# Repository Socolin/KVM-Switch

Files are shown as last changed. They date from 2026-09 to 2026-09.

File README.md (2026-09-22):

# KVM Switch

A KVM Switch for any HID device built with multiple [Raspberry Pi Pico 2](https://www.raspberrypi.com/products/raspberry-pi-pico-2/)

## Status

This project is still in development. The code is almost done, and I need to design the PCB.

Photo of the KVM Switch on a breadboard

So far I can use it as a KVM switch. I can select the computer to use with a keyboard shortcut. I was not able to
test with exotic keyboard / mouse yet, but those should be supported.

The detailed documentation is available at [doc/technical.md](doc/technical.md).

The remaining tasks are: 
- Test with 2 nodes (switch between 3 computers).
- Design PCB for 1 node (and maybe for 2 nodes later)
- Test with 3 hid devices.
- Test `TUD_OPT_HIGH_SPEED`

## Build

### Prerequisites

- cmake
- Clone https://github.com/raspberrypi/pico-sdk
- Clone https://github.com/raspberrypi/picotool

### Build

```sh
git clone git@github.com:Socolin/KVM-Switch.git
cd KVM-Switch
git submodule update --init --recursive
mkdir build
cd build
cmake .. -DPICO_BOARD=pico2 -DPICO_SDK_PATH={PATH_TO_PICOSDK} -DPICOTOOL_FETCH_FROM_GIT_PATH={PATH_TO_PICOTOOL}
make -j
# Then output is in src/node and src/controller
```

### Flash

To simplify flashing both, you can use the serial number of your pico with `picotool info -a` the serial will look like `46AA0E6255B66826`

```sh
picotool load --ser $PICO_PI_NODE_SERIAL -f -x src/node/kvm_node.uf2;
picotool load --ser $PICO_PI_CONTROLLER_SERIAL -f -x src/controller/kvm_controller.uf2;
```

## Hardware Architecture

### 2 Nodes With 2 HIDs

[See Schematic](doc/2_nodes_2_hid/2_nodes_2_hid.pdf)

### 2 Nodes With 3 HIDs

[See Schematic](doc/2_nodes_3_hid/2_nodes_3_hid.pdf)

### 3 Nodes With 3 HIDs

[See Schematic](doc/3_nodes_3_hid/3_nodes_3_hid.pdf)

## Software Architecture

Diagram showing the software architecture of the project. Detailing which core execute which part and which the architecture of node and controller boards

## Configuration UI

The KVM Switch can be configured through a web UI. It can be accessed with a web browser supporting WebUSB.
You can access it at https://socolin.github.io/KVM-Switch/ (You need to use a browser supporting WebUSB)
The code of the config UI is in `tools/configurator`

Web UI

### Build

If you need to build the tool, you need [Node.js 24](https://nodejs.org/) then run those commands

```
cd tools/configurator
npm install
npm run start
```

Then access it at http://localhost:4200 (You need to use a browser supporting WebUSB)

## AI Usage

Basically, I see AI as a tool, and I have fun writing code, so:

- All the code in `src/` is written by a human.
- AI was used as a learning assistant, to help understand and learn all the USB / HID / Electronic stuff.
- AI was used to review the code.
- AI was used to generate some test cases (but the test logic is human-made) (see `AI-generated` comments).

## History

This project started to fix an issue I had with my current commercial KVM switch, that is the delay to switch between
2 computers; I wanted a shortcut to switch instantaneously. This project is also an opportunity for me to learn a some
few things with electronic and discover dev on a microcontroller. Feel free to provide any feedback, as I'm still
learning.

I first tried to use CH9329 and CH9350 to avoid all the USB parts and get this done quickly. However, during
my testing I discovered that the CH9329 has a HID descriptor that does not expose all the features I wanted (like the
mouse pan) and the CH9350 felt the same way. So I learnt a lot about HID descriptors, tinyUSB, etc… And, now this project
should support any HID device (not just keyboard and mouse) like Gamepad etc… I kept the code I used to use those chips
in `src/legacy` if anyone need this, feel free to use it

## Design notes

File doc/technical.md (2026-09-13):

# Technical

## Controller / Node

Each Pico PI 2 can handle one USB Device. So to connect the KVM Switch to multiple computers, 1 Pico PI is used per
computer.

The main Pico is the one with the USB ports for the HID devices, it's named the Controller (`src/controller`), and any
additional pico pi is named a Node (`src/node`).

The Controller and the Nodes are communicating using SPI. On the Controller it's using the `spi0` with the default pins
And on the first nodes it's using the `spi1` with the GPIO 12,13,14,15 to simplify cable management between the two
boards.

Each node also uses 2 GPIO:

- `spi_ready_gpio` use to notify the Controller when the node is listening on SPI and the controller can communicate
  with them.
- `data_available_gpio` use to notify the Controller when the node has data available to be read.

When there are two or more nodes, the controller uses another GPIO (`spi_selector_gpio`) to select which node to
communicate with.

When the Controller boots, it restarts all the nodes (with GPIO 15 connected to `RUN` on the nodes) and waits for them
to be ready (Waiting for an `GPIO_IRQ_EDGE_RISE` event on `spi_ready_gpio`)

## USB Device – Connected to a computer

See `usb_device.c`

The USB Port used to act as a USB device from a computer point of view is the micro USB port that comes with the
PICO-PI.
This allows running some logic on the same core that handles this usb port with Tiny USB, since this USB port is managed
by the RP2350 the timings are not as critical as when using Pico-PIO-USB.

## USB Host – Connected to the HID Devices (Keyboard / Mouse / ...)

See `usb_host.c`

The USB Host part is used to handle the HID Devices plugged into the KVM Switch. Pico-PIO-USB with TinyUSB is used to
handle the USB communication with the HID Devices. And the Core 1 on the Controller is dedicated to handle the USB
communication with the HID Devices.

The USB ports have both D+ and D-, pulled down to act as a USB host.

## HID Devices

The HID devices are connected to the USB Host part of the Controller. When a HID device is mounted, the controller reads
the HID report descriptor for every HID interface and then exposes the report descriptors as its own on the computer
side (see `hid_manager.c`). Then, when an HID Device is sending a report (when a key is pressed, for example), the
report is forwarded as-is to the selected computer.

The HID report descriptor is also decoded (see `hid_report_descriptor.c`) and any keyboard report is then interpreted to
detect if a shortcut has been pressed (see `kvm_switch_config.c`).

## WebUSB

See `web_usb_handler.c`

To allow a simple configuration of the KVM Switch, WebUSB is used to communicate with the KVM Switch from a web browser.
A Vendor interface is exposed to the computer (see `#if CFG_TUD_VENDOR` blocks in `usb_device.c`).

When a config is changed, the config is then saved to the flash. It's written on the fourth sector from the end of the
flash (see `config_persistence.c`).

## Cpu Core Usage

On the controller core 0 runs the main logic, core 1 is dedicated to handle the USB communication with the HID Devices.
On the nodes, core 0 runs the main logic, and core 1 is dedicated to the SPI communication with the controller.

## System clock

The system clock is set to 144 MHz because Pico-PIO-USB needs a multiple of 12 MHz.

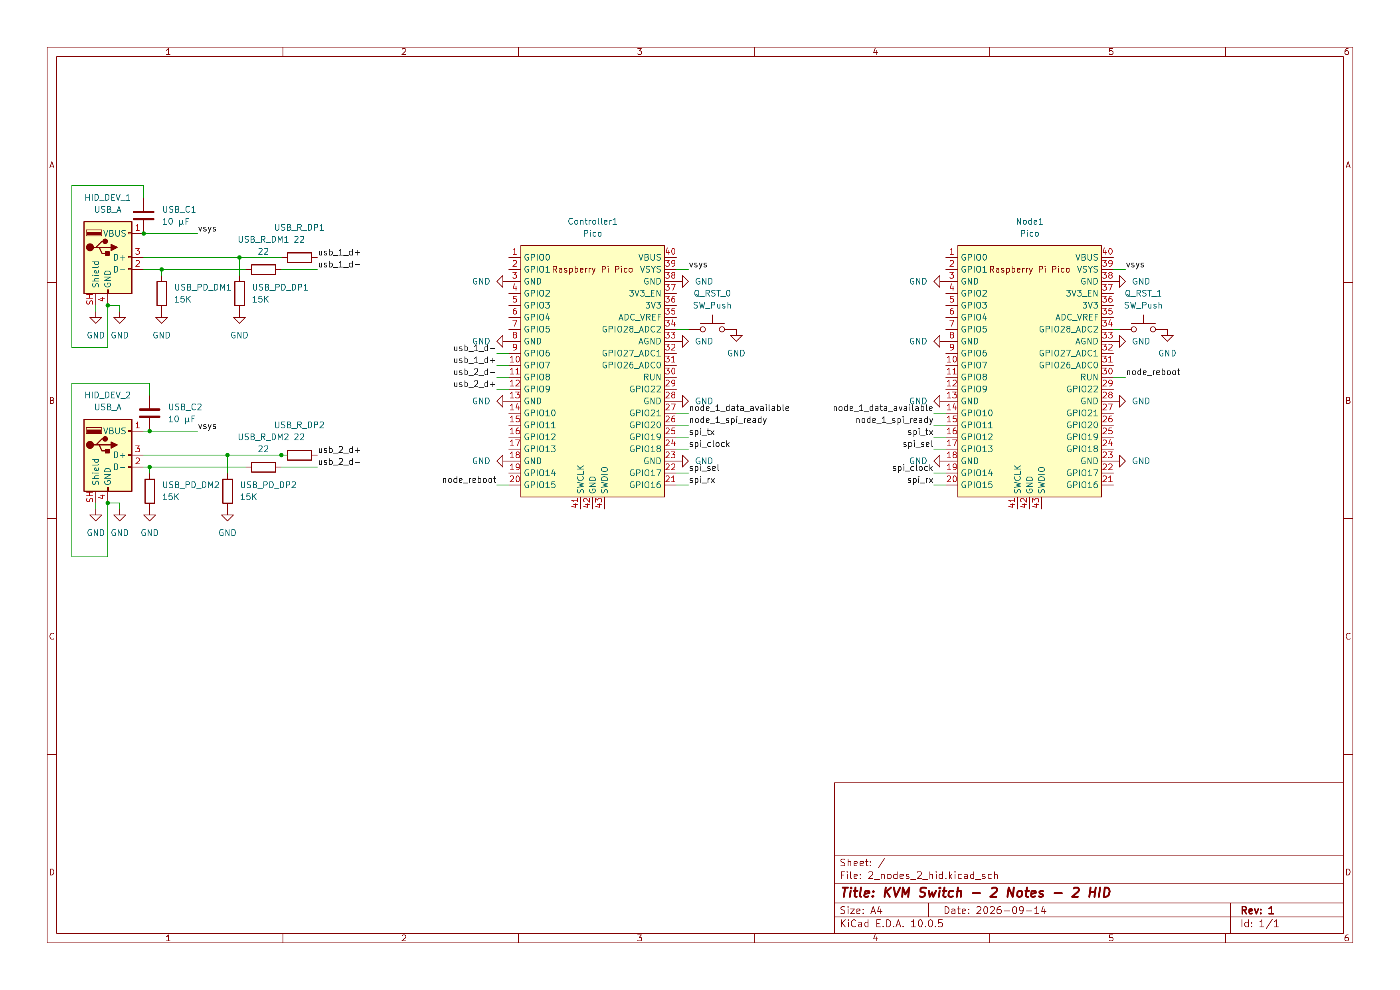
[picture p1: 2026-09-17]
doc/img/schematic.png

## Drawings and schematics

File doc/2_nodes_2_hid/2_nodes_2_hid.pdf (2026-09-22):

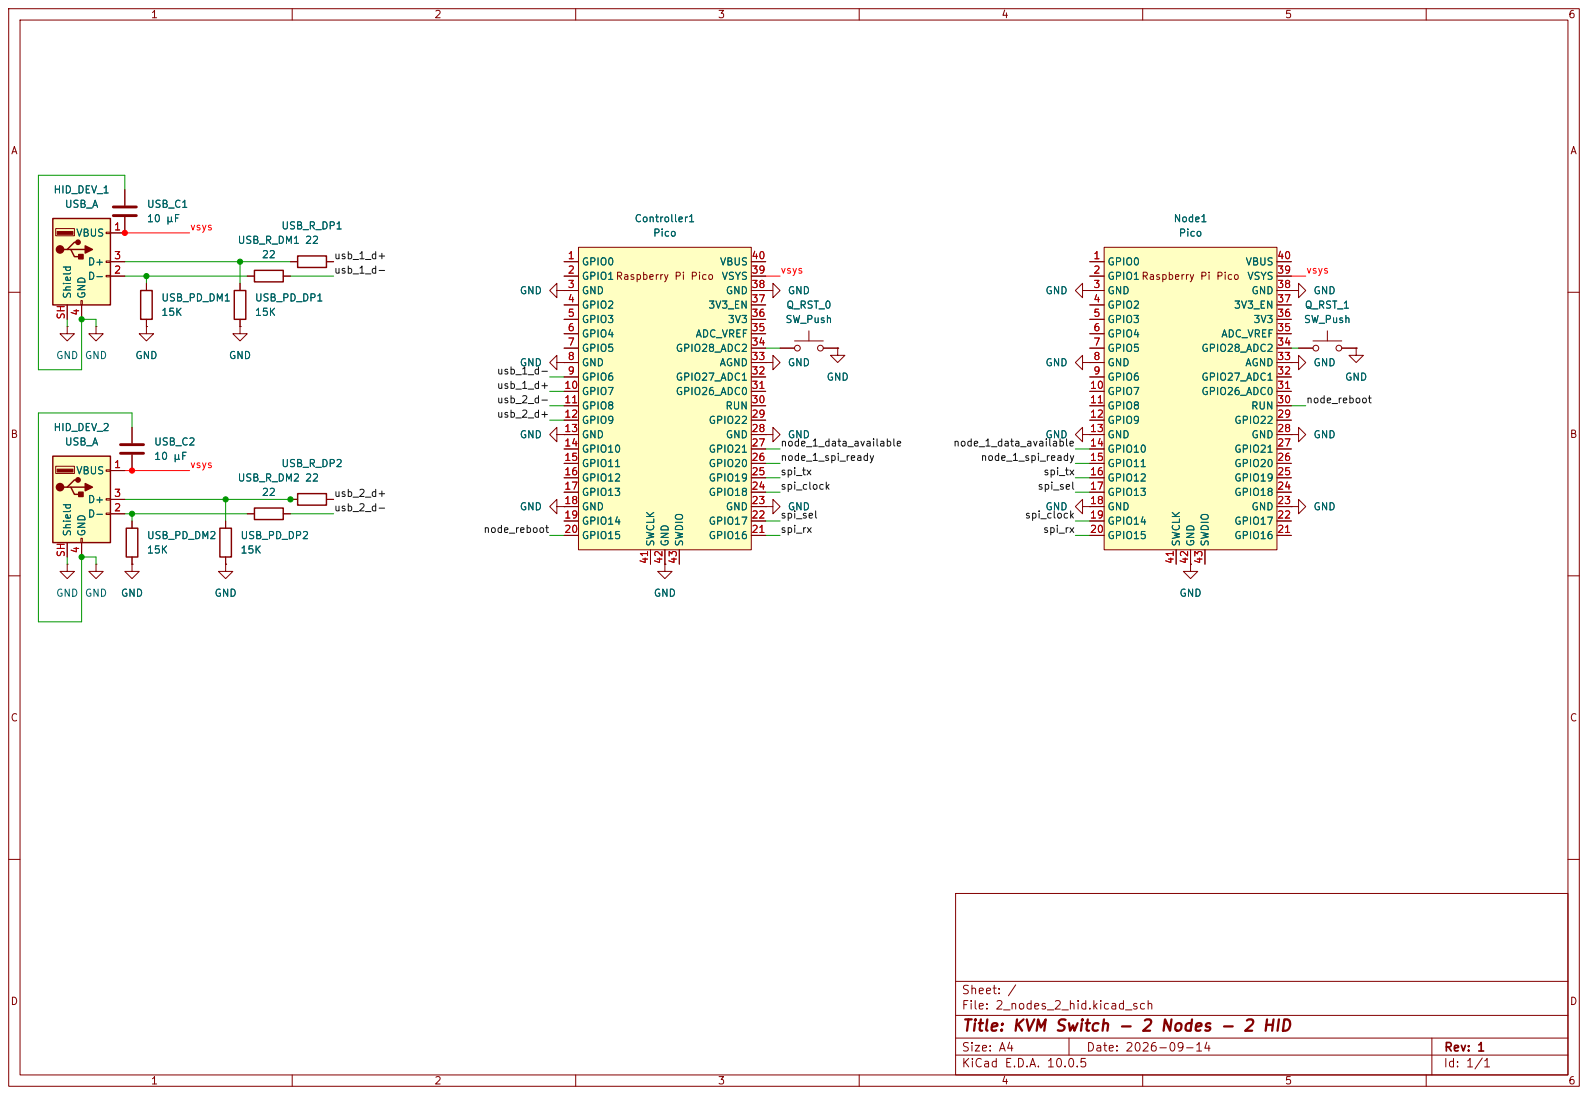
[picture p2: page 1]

Sheet: /
File: 2_nodes_2_hid.kicad_sch
Title: KVM Switch - 2 Nodes - 2 HID

Size: A4 | Rev: 1
KiCad E.D.A. 10.0.5 | Id: 1/1

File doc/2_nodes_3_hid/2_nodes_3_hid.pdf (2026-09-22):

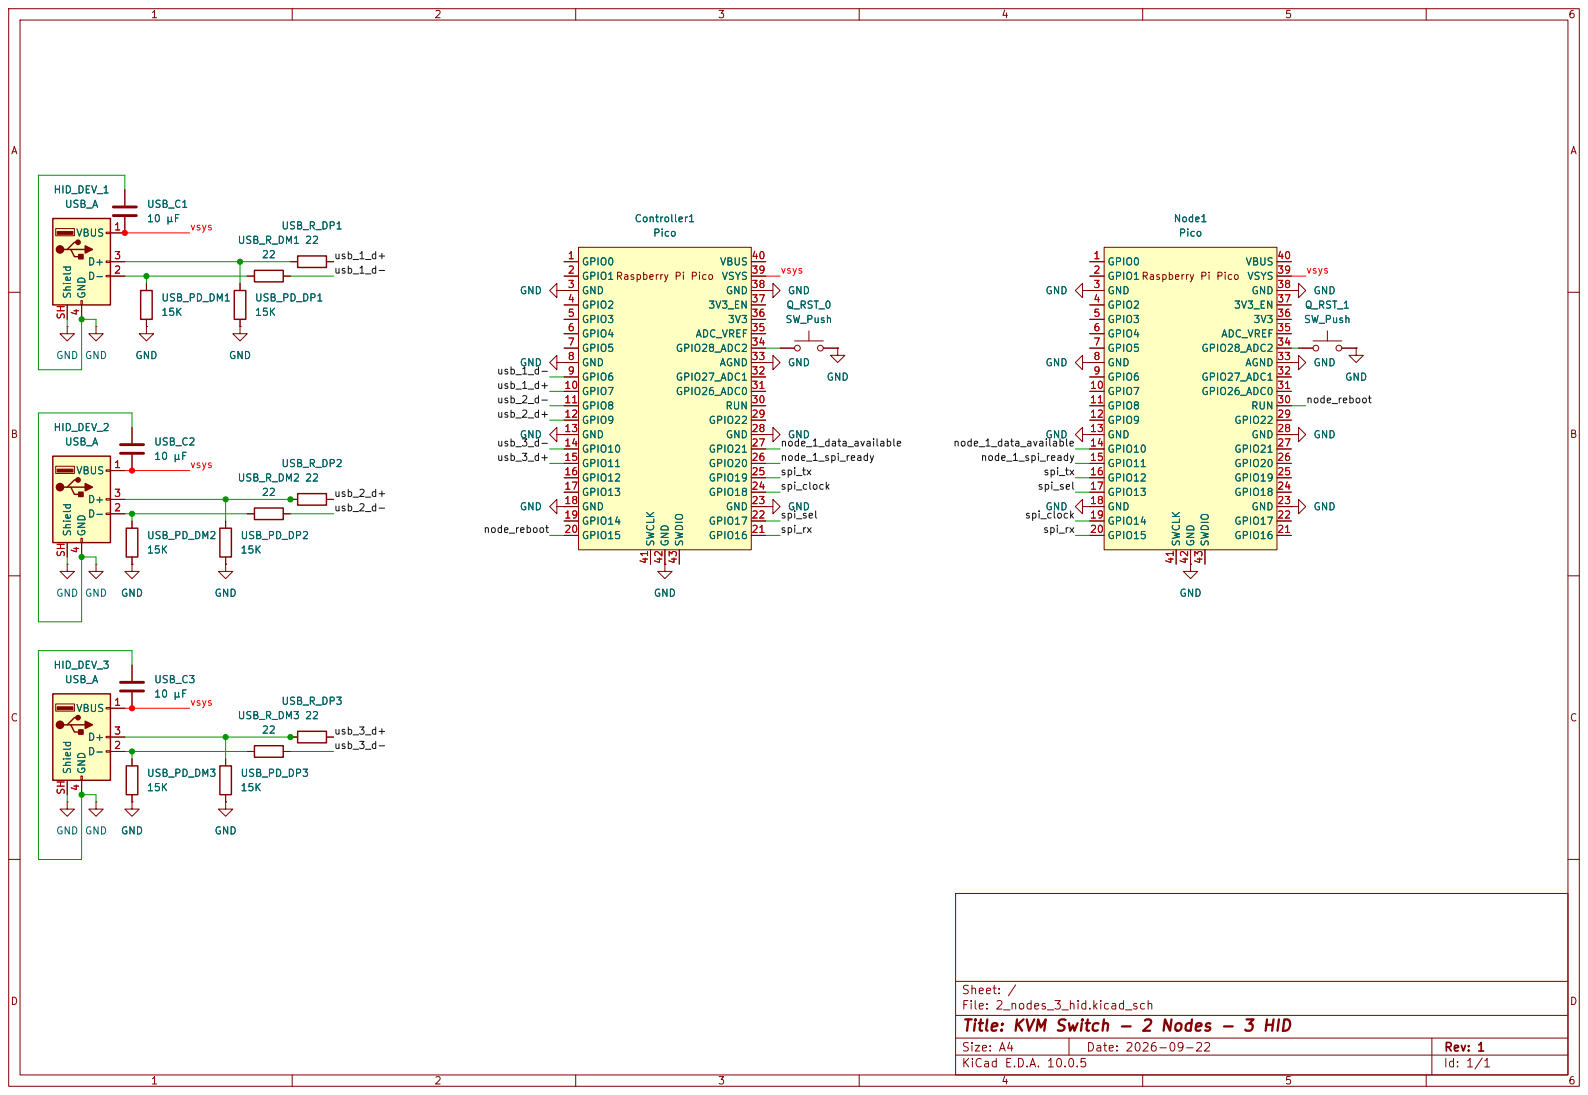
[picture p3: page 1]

Sheet: /
File: 2_nodes_3_hid.kicad_sch
Title: KVM Switch - 2 Nodes - 3 HID

Size: A4 | Rev: 1
KiCad E.D.A. 10.0.5 | Id: 1/1

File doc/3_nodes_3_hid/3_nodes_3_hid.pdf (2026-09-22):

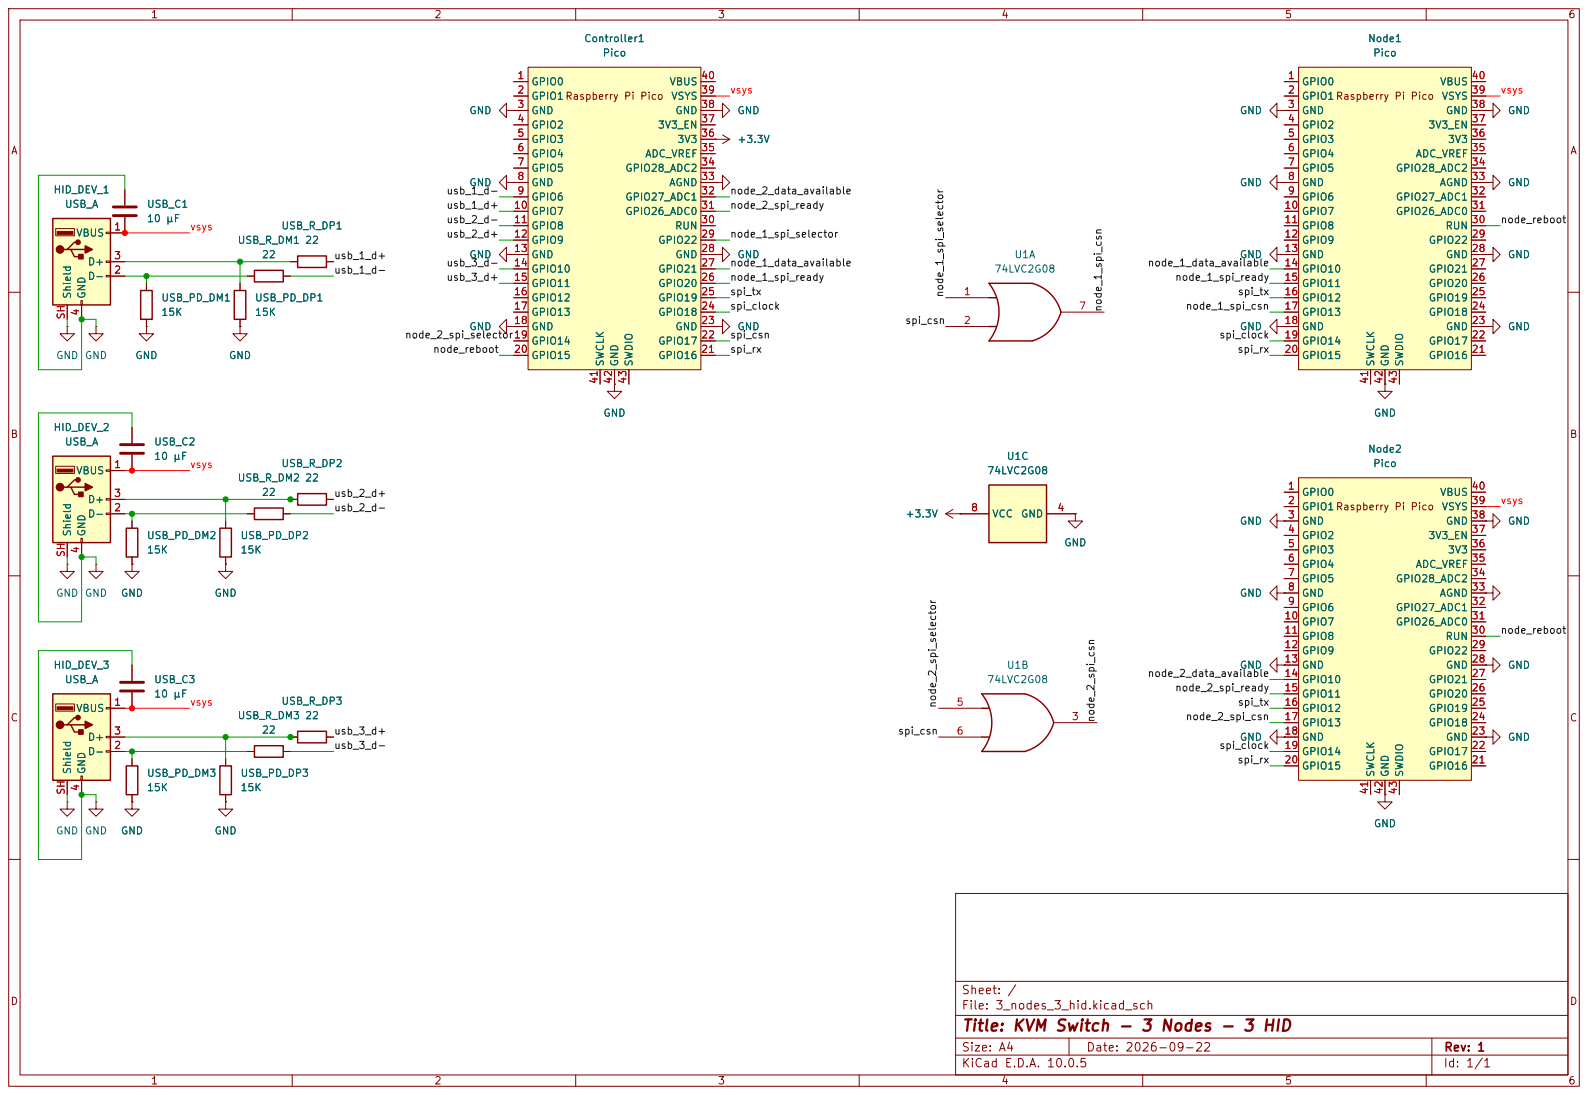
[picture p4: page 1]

Sheet: /
File: 3_nodes_3_hid.kicad_sch
Title: KVM Switch - 3 Nodes - 3 HID

Size: A4 | Rev: 1
KiCad E.D.A. 10.0.5 | Id: 1/1

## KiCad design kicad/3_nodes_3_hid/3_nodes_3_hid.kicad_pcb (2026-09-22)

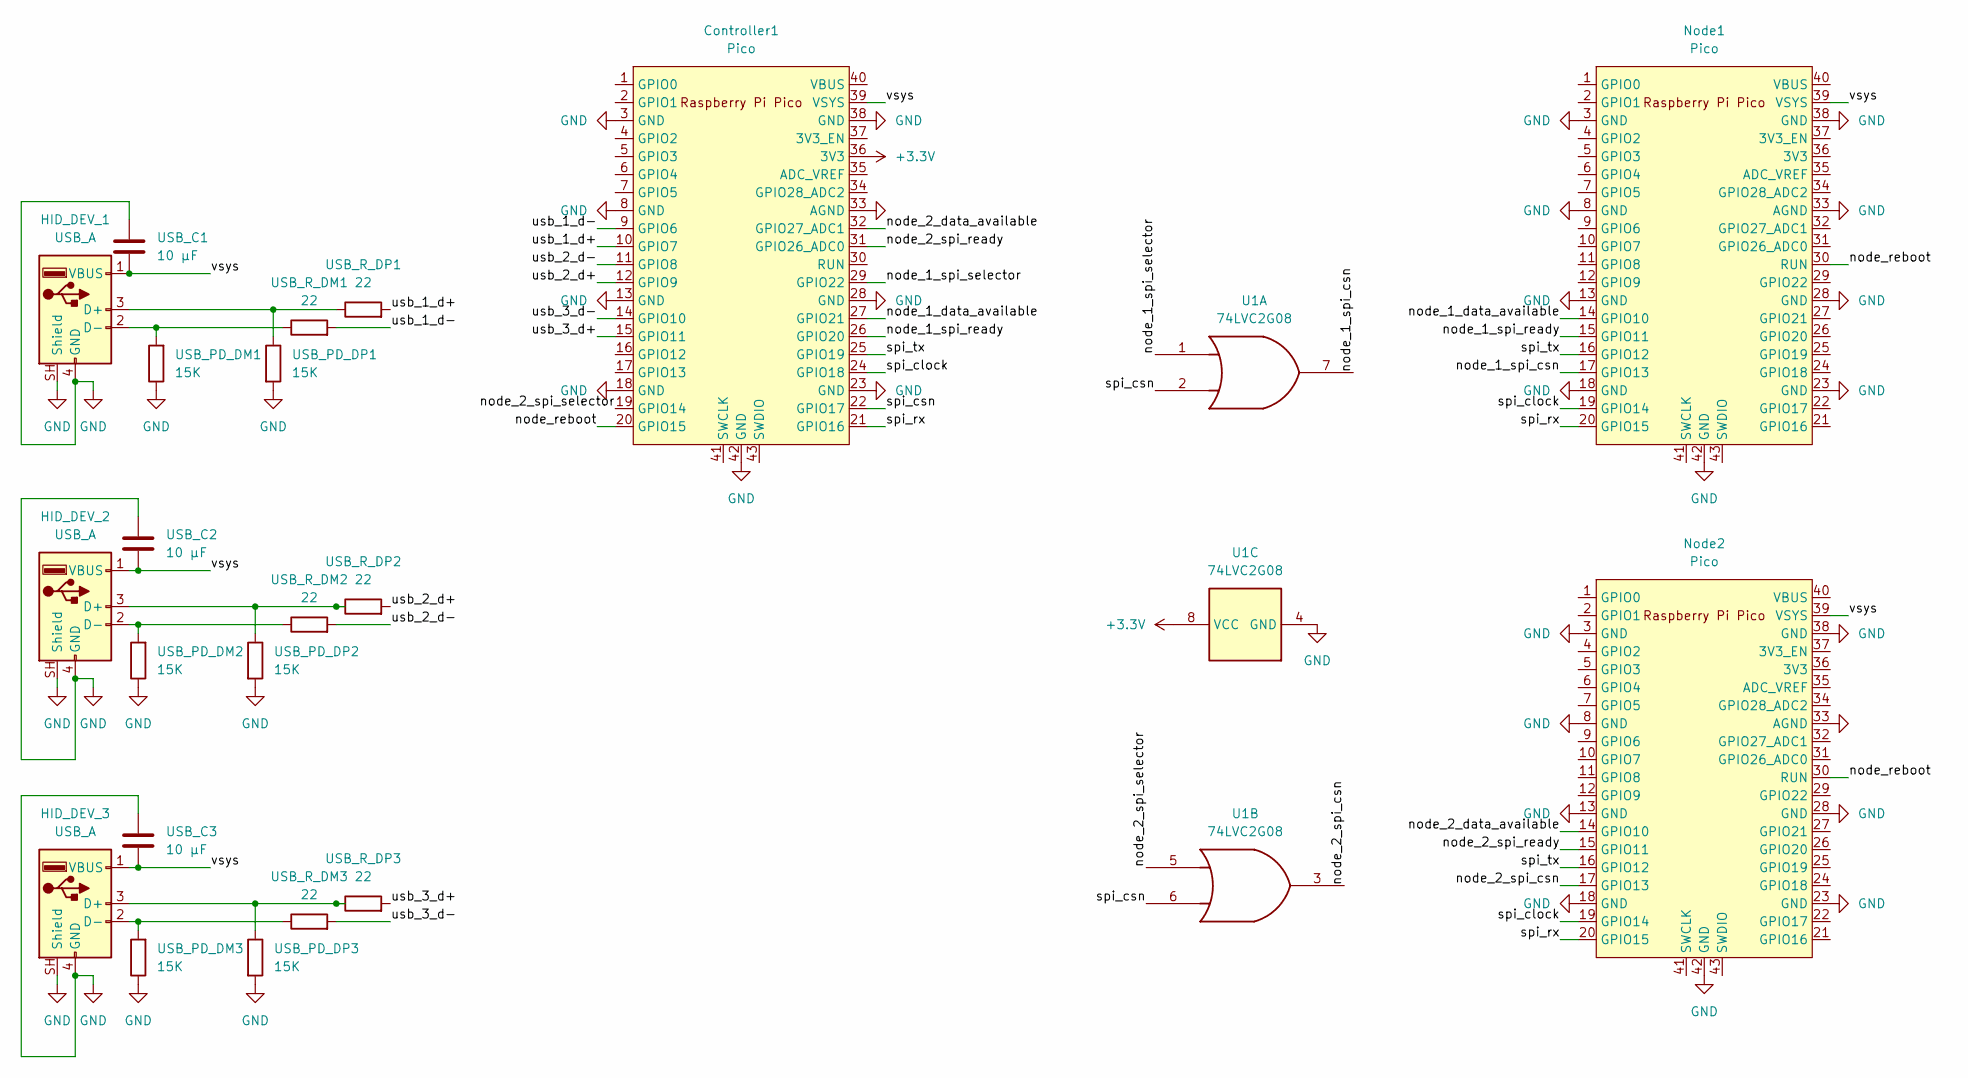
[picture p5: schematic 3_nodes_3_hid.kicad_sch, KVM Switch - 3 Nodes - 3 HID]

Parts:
Controller1: Pico; RPi_Pico_SMD_TH
HID_DEV_1, HID_DEV_2, HID_DEV_3: USB_A; USB_A_Molex_67643_Horizontal
Node1, Node2: Pico; RPi_Pico_SMD_TH
U1: 74LVC2G08; TSSOP-8_4.4x3mm_P0.65mm
USB_C1, USB_C2, USB_C3: 10 µF; C_1206_3216Metric_Pad1.33x1.80mm_HandSolder
USB_PD_DM1, USB_PD_DM2, USB_PD_DM3: 15K; R_1206_3216Metric_Pad1.30x1.75mm_HandSolder
USB_PD_DP1, USB_PD_DP2, USB_PD_DP3: 15K; R_1206_3216Metric_Pad1.30x1.75mm_HandSolder
USB_R_DM1, USB_R_DM2, USB_R_DM3: 22; R_1206_3216Metric_Pad1.30x1.75mm_HandSolder
USB_R_DP1, USB_R_DP2, USB_R_DP3: 22; R_1206_3216Metric_Pad1.30x1.75mm_HandSolder

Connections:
+3.3V: Controller1.36 (3V3), U1.8 (VCC)
/node_1_data_available: Controller1.27 (GPIO21), Node1.14 (GPIO10)
/node_1_spi_csn: Node1.17 (GPIO13), U1.7
/node_1_spi_ready: Controller1.26 (GPIO20), Node1.15 (GPIO11)
/node_1_spi_selector: Controller1.29 (GPIO22), U1.1
/node_2_data_available: Controller1.32 (GPIO27_ADC1), Node2.14 (GPIO10)
/node_2_spi_csn: Node2.17 (GPIO13), U1.3
/node_2_spi_ready: Controller1.31 (GPIO26_ADC0), Node2.15 (GPIO11)
/node_2_spi_selector: Controller1.19 (GPIO14), U1.5
/node_reboot: Controller1.20 (GPIO15), Node1.30 (RUN), Node2.30 (RUN)
/spi_clock: Controller1.24 (GPIO18), Node1.19 (GPIO14), Node2.19 (GPIO14)
/spi_csn: Controller1.22 (GPIO17), U1.2, U1.6
/spi_rx: Controller1.21 (GPIO16), Node1.20 (GPIO15), Node2.20 (GPIO15)
/spi_tx: Controller1.25 (GPIO19), Node1.16 (GPIO12), Node2.16 (GPIO12)
/usb_1_d+: Controller1.10 (GPIO7), USB_R_DP1.2
/usb_1_d-: Controller1.9 (GPIO6), USB_R_DM1.2
/usb_2_d+: Controller1.12 (GPIO9), USB_R_DP2.2
/usb_2_d-: Controller1.11 (GPIO8), USB_R_DM2.2
/usb_3_d+: Controller1.15 (GPIO11), USB_R_DP3.2
/usb_3_d-: Controller1.14 (GPIO10), USB_R_DM3.2
/vsys: Controller1.39 (VSYS), HID_DEV_1.1 (VBUS), HID_DEV_2.1 (VBUS), HID_DEV_3.1 (VBUS), Node1.39 (VSYS), Node2.39 (VSYS), USB_C1.2, USB_C2.2, USB_C3.2
GND: Controller1.3 (GND), Controller1.8 (GND), Controller1.13 (GND), Controller1.18 (GND), Controller1.23 (GND), Controller1.28 (GND), Controller1.33 (AGND), Controller1.38 (GND), Controller1.42 (GND), HID_DEV_1.4 (GND), HID_DEV_1.SH (Shield), HID_DEV_2.4 (GND), HID_DEV_2.SH (Shield), HID_DEV_3.4 (GND), HID_DEV_3.SH (Shield), Node1.3 (GND), Node1.8 (GND), Node1.13 (GND), Node1.18 (GND), Node1.23 (GND), Node1.28 (GND), Node1.33 (AGND), Node1.38 (GND), Node1.42 (GND), Node2.3 (GND), Node2.8 (GND), Node2.13 (GND), Node2.18 (GND), Node2.23 (GND), Node2.28 (GND), Node2.33 (AGND), Node2.38 (GND), Node2.42 (GND), U1.4 (GND), USB_C1.1, USB_C2.1, USB_C3.1, USB_PD_DM1.1, USB_PD_DM2.1, USB_PD_DM3.1, USB_PD_DP1.2, USB_PD_DP2.2, USB_PD_DP3.2
unnamed: HID_DEV_1.3 (D+), USB_PD_DP1.1, USB_R_DP1.1
unnamed: HID_DEV_1.2 (D-), USB_PD_DM1.2, USB_R_DM1.1
unnamed: HID_DEV_2.3 (D+), USB_PD_DP2.1, USB_R_DP2.1
unnamed: HID_DEV_2.2 (D-), USB_PD_DM2.2, USB_R_DM2.1
unnamed: HID_DEV_3.3 (D+), USB_PD_DP3.1, USB_R_DP3.1
unnamed: HID_DEV_3.2 (D-), USB_PD_DM3.2, USB_R_DM3.1

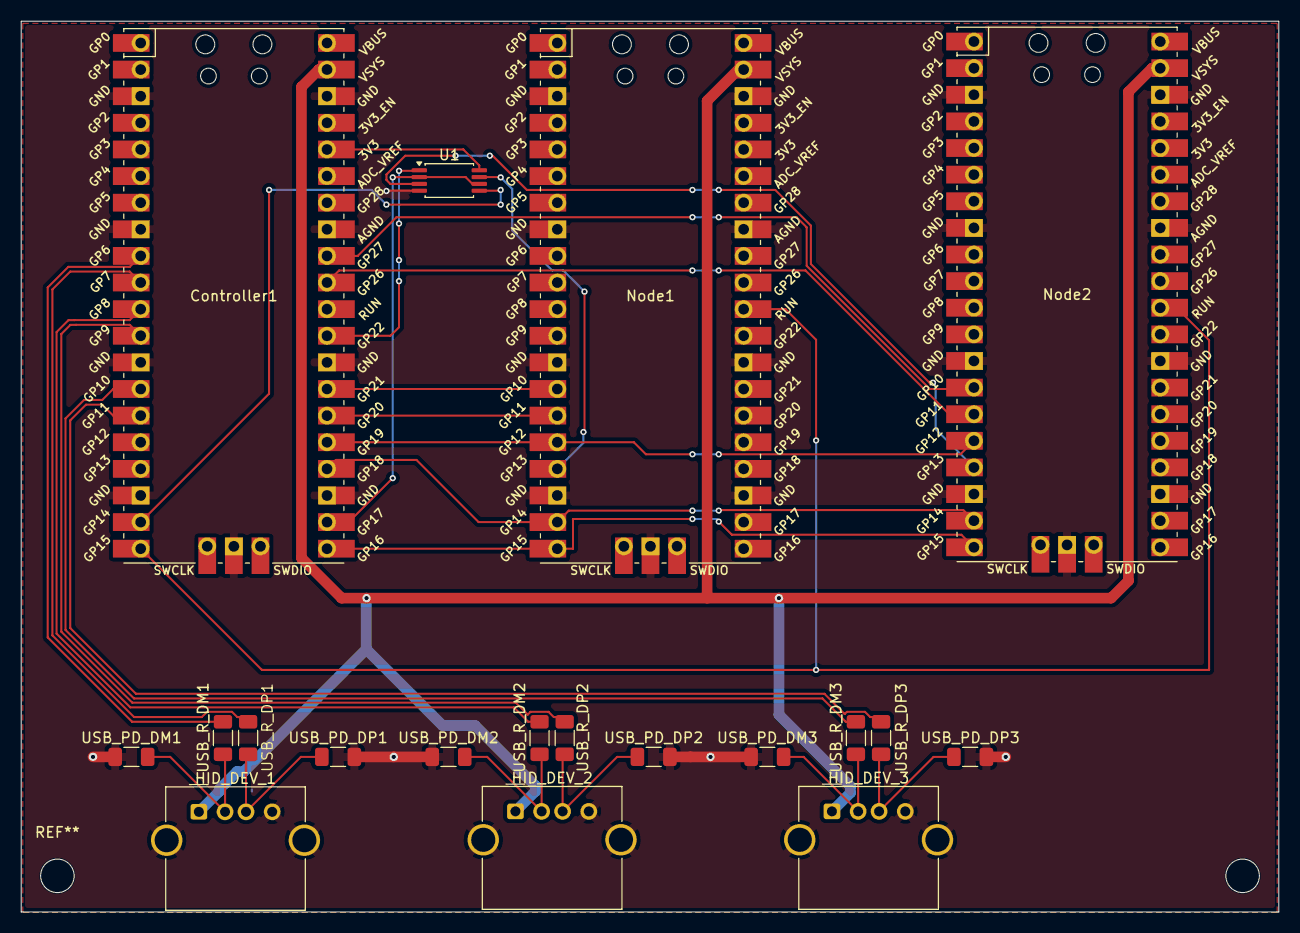
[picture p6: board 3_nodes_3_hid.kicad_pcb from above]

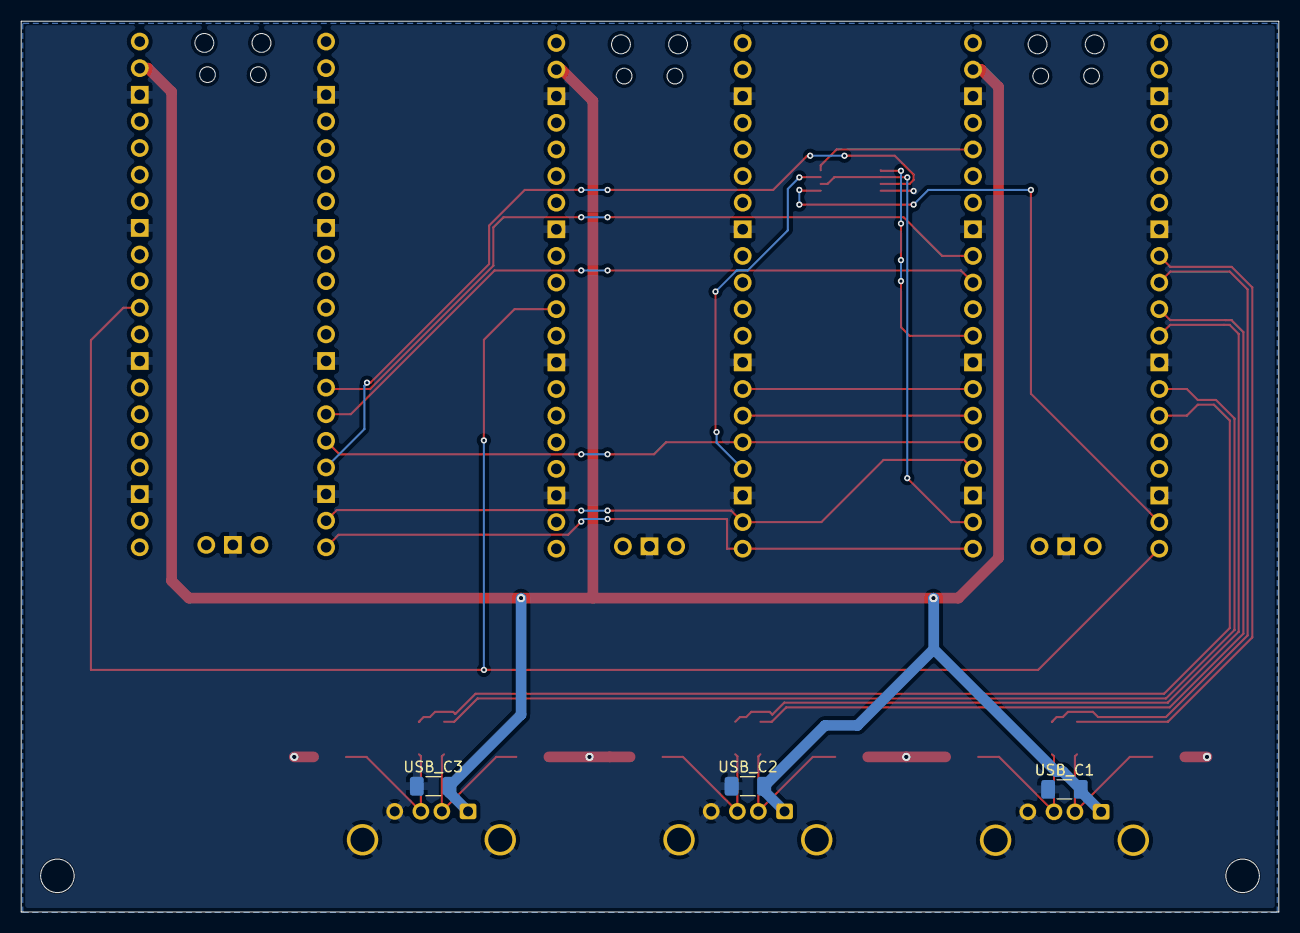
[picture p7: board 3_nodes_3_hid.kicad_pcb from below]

Board: 2 copper layers, 120.0 x 85.0 mm, 22 parts (3 on the bottom side), 28 nets.

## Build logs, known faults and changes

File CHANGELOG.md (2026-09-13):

## [Unreleased]

## [1.0.0] - 2026-09-13

- KVM switch built from Raspberry Pi Pico 2 boards: one controller and one or more nodes (one per computer), linked over SPI.
- Support for any HID device (keyboard, mouse, gamepad, …) through PIO USB.
- Switch the active computer instantly with a keyboard shortcut.
- Shortcut action to change which computer a specific device is forwarded to.
- Web configurator over WebUSB (`tools/configurator`):
    - Edit general settings and keyboard shortcuts.
    - Inspect each device's HID descriptor, with decoded report fields.
    - View device logs, filterable by level.
- Configuration saved in flash and kept after a reboot.

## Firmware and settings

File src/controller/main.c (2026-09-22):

#include "hid_device_manager.h"
#include "pico/flash.h"
#if !PICO_RP2350
#error "This targets the Pico 2 (RP2350) only"
#endif

#include "bsp/board_api.h"
#include "hardware/clocks.h"
#include "hardware/watchdog.h"
#include "pico/stdlib.h"
#include "pico/multicore.h"
#include <string.h>

#include "../shared_usb/usb_device.h"

#include "computer_manager.h"
#include "hid_manager.h"
#include "kvm_switch_config.h"
#include "kvm_switch_controller.h"
#include "logger.h"
#include "node_link_ctrl.h"
#include "quick_reset_button.h"
#include "usb_host.h"
#include "version.h"
#include "git_version.h"

// ╔══════════════════════════════════╗
// ║     Callback for usb_device      ║
// ╚══════════════════════════════════╝

static void on_usb_device_set_report(
    uint8_t kvm_hid_idx,
    uint8_t report_id,
    uint8_t report_type,
    uint8_t const *report_data,
    uint16_t report_data_len
);

static void on_usb_device_set_hid_protocol(
    uint8_t kvm_hid_idx,
    uint8_t hid_protocol
);

static void on_usb_device_mounted();

static void on_usb_device_unmounted();

// ╔══════════════════════════════════╗
// ║            Main Logic            ║
// ╚══════════════════════════════════╝

static void core1_main() {
    log_info("Starting USB Host on core 1");

    flash_safe_execute_core_init();
    usb_host_init();

    log_info("USB Host ready");

    log_debug("Starting main loop on core 1");

    while (true) {
        usb_host_task();
    }
}

int main() {
    // To use Pico-PIO-USB the system clock should be multiple of 12MHz.
    // USB requires a very precise clock and since PIO are working at a multiple
    // of the core frequency if it's not a multiple of 12MHz, some cycle will be longer or shorter and it will
    // create error when writing / reading usb.
    set_sys_clock_khz(144'000, true);

    watchdog_enable(5000, 1);

    stdio_init_all();

    logger_init(LOG_LEVEL_DEBUG, LOG_LEVEL_INFO);
    quick_reset_button_init();

    log_info("KVM controller is starting");
    logf_info("Version: %s", GIT_HASH);
    logf_info("Built at : %s", BUILD_DATE);

    computer_manager_init();
    computer_manager_configure_computer(1, 22, 20, 21);
#if MAX_COMPUTER > 2
    computer_manager_configure_computer(2, 14, 26, 27);
#endif

    hid_device_manager_init();
    hid_mgr_init();
    kvm_config_init();
    kvm_switch_controller_init();
    node_link_ctrl_init();

    usb_device_init(
        on_usb_device_set_report,
        on_usb_device_set_hid_protocol,
        on_usb_device_mounted,
        on_usb_device_unmounted
    );

    log_info("Initializing board");

    board_init();

    multicore_reset_core1();
    multicore_launch_core1(core1_main);

    board_init_after_tusb();

    log_info("KVM Core ready");

    log_debug("Restarting KVM nodes and waiting for themn to be up");
    node_link_ctrl_restart_nodes();

    log_debug("Starting main loop on core 0");

    while (true) {
        usb_device_task();
        kvm_switch_controller_task();
        node_link_ctrl_task();
        watchdog_update();
    }
}


// ╔══════════════════════════════════╗
// ║     Callbacks implementations    ║
// ╚══════════════════════════════════╝

static void on_usb_device_set_report(
    const uint8_t kvm_hid_idx,
    const uint8_t report_id,
    const uint8_t report_type,
    uint8_t const *report_data,
    const uint16_t report_data_len
) {
    kvm_switch_controller_enqueue_computer_set_report(
        LOCAL_COMPUTER_ID,
        kvm_hid_idx,
        report_id,
        report_type,
        report_data,
        report_data_len
    );
}

static void on_usb_device_set_hid_protocol(
    const uint8_t kvm_hid_idx,
    const uint8_t hid_protocol
) {
    kvm_switch_controller_enqueue_computer_set_hid_protocol(
        LOCAL_COMPUTER_ID,
        kvm_hid_idx,
        hid_protocol
    );
}

static void on_usb_device_mounted(
) {
    kvm_switch_controller_enqueue_usb_device_mounted();
}

static void on_usb_device_unmounted(
) {
    kvm_switch_controller_enqueue_usb_device_unmounted();
}

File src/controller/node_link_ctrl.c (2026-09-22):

#include "node_link_ctrl.h"

#include <math.h>
#include <string.h>

#include "hardware/spi.h"
#include "hardware/gpio.h"

#include "computer_manager.h"
#include "gpio_utils.h"
#include "hid_manager.h"
#include "kvm_switch_controller.h"
#include "logger.h"
#include "node_link.h"

typedef struct {
    node_link_t link;
    bool node_ready[MAX_COMPUTER];
} node_link_ctrl_t;

static node_link_ctrl_t ctrl;

static void node_link_ctrl_process_received_message(const node_link_msg_t *message, void *udata);

void node_link_ctrl_init() {
    for (int i = 1; i < MAX_COMPUTER; i++) {
        const computer_t *computer = computer_manager_get_computer(i);

        gpio_init(computer->spi_selector_gpio);
        gpio_set_dir(computer->spi_selector_gpio, GPIO_OUT);
        gpio_put(computer->spi_selector_gpio, 1);

        gpio_init(computer->spi_ready_gpio);
        gpio_set_dir(computer->spi_ready_gpio, GPIO_IN);
        gpio_pull_down(computer->spi_ready_gpio);

        gpio_init(computer->data_available_gpio);
        gpio_set_dir(computer->data_available_gpio, GPIO_IN);
        gpio_pull_down(computer->data_available_gpio);
    }

    node_link_init_controller(&ctrl.link, spi0, node_link_ctrl_process_received_message);
}

#define RESTART_NODES_GPIO 15

static void node_link_ctrl_irq_handler(
    [[maybe_unused]] uint gpio,
    [[maybe_unused]] uint32_t event_mask,
    const void *user_data
) {
    const computer_t *computer = user_data;
    if (event_mask & GPIO_IRQ_EDGE_RISE) {
        ctrl.node_ready[computer->computer_id] = true;
    }
}

void node_link_ctrl_restart_nodes() {
    log_info("Restarting nodes to be ready");
    for (int i = 1; i < MAX_COMPUTER; i++) {
        const computer_t *computer = computer_manager_get_computer(i);
        ctrl.node_ready[i] = false;
        gpio_util_set_handler(computer->spi_ready_gpio, GPIO_IRQ_EDGE_RISE, node_link_ctrl_irq_handler, computer);
    }

    gpio_init(RESTART_NODES_GPIO);
    gpio_set_dir(RESTART_NODES_GPIO, GPIO_OUT);
    sleep_us(10);
    for (int i = 1; i < MAX_COMPUTER; i++) {
        ctrl.node_ready[i] = false;
    }
    gpio_set_dir(RESTART_NODES_GPIO, GPIO_IN);

    log_info("Waiting for nodes to be ready..");
    for (int i = 1; i < MAX_COMPUTER; i++) {
        const uint64_t wait_start = time_us_64();
        while (!ctrl.node_ready[i]) {
            if (time_us_64() - wait_start > 3'000'000) {
                logf_error("Timeout waiting for node %d to be ready", i);
                break;
            }
            tight_loop_contents();
        }
    }
    for (int i = 1; i < MAX_COMPUTER; i++) {
        const computer_t *computer = computer_manager_get_computer(i);
        gpio_util_clear_handler(computer->spi_ready_gpio);
    }

    log_info("All nodes are ready");
}

static void node_link_ctrl_process_received_message(
    const node_link_msg_t *message,
    void *udata
) {
    logf_debug("opcode: %u, data_len: %u", message->header.opcode, message->header.data_len);
    const uint8_t computer_id = *(uint8_t *) udata;

    switch (message->header.opcode) {
        case NL_NODE_MESSAGE_OP_INIT: {
            computer_manager_init_computer(computer_id);
            node_link_ctrl_enqueue_send_init(computer_id);
            kvm_switch_controller_enqueue_computer_ready(computer_id);
            break;
        }
        case NL_NODE_MESSAGE_OP_SET_REPORT: {
            auto const message_data = (nl_node_msg_hid_set_report_data_t *) message->data;
            kvm_switch_controller_enqueue_computer_set_report(
                computer_id,
                message_data->kvm_hid_idx,
                message_data->report_id,
                message_data->report_type,
                message->extra_data[0].data,
                message->extra_data[0].data_len
            );
            break;
        }
        case NL_NODE_MESSAGE_OP_SET_HID_PROTOCOL: {
            auto const message_data = (nl_node_msg_hid_set_hid_protocol_data_t *) message->data;
            kvm_switch_controller_enqueue_computer_set_hid_protocol(
                computer_id,
                message_data->kvm_hid_idx,
                message_data->hid_protocol
            );
            break;
        }
        default: {
            logf_error("invalid opcode: %04x", message->header.opcode);
            break;
        }
    }
}


void node_link_ctrl_task() {
    for (uint8_t computer_id = 1; computer_id < MAX_COMPUTER; computer_id++) {
        computer_t *computer = computer_manager_get_computer(computer_id);

        const bool spi_ready = gpio_get(computer->spi_ready_gpio);
        if (!spi_ready) {
            continue;
        }

        node_link_spi_select_target(&ctrl.link, computer->spi_ready_gpio, computer->spi_selector_gpio);

        const bool data_available = gpio_get(computer->data_available_gpio);

        node_link_msg_t message;
        if (queue_try_peek(&computer->message_queue, &message)) {
            if (!node_link_send_message_blocking(&ctrl.link, &message, &computer_id)) {
                node_link_drain_buffer(&ctrl.link);
            } else {
                queue_remove_blocking(&computer->message_queue, nullptr);
                node_link_dispose_message(&message);
            }
        } else if (data_available) {
            if (!node_link_send_message_blocking(&ctrl.link, nullptr, &computer_id)) {
                node_link_drain_buffer(&ctrl.link);
            }
        }
    }
}


// ╔══════════════════════════════════╗
// ║     Enqueue message to send      ║
// ╚══════════════════════════════════╝

static bool node_link_ctrl_enqueue_message(
    const uint8_t computer_id,
    const node_link_ctrl_msg_opcode_t opcode,
    const void *data,
    const size_t data_len,
    const void *extra_data_1,
    const size_t extra_data_1_len,
    const bool should_free_once_sent
) {
    computer_t *computer = computer_manager_get_computer(computer_id);
    if (computer->state == COMPUTER_STATE_NOT_CONNECTED) {
        logf_warning("Node handling computer %u is not connected", computer_id);
        return false;
    }
    if (queue_is_full(&computer->message_queue)) {
        logf_warning("Message queue of computer %u is full", computer_id);
        return false;
    }

    logf_debug("opcode: %u, data_len: %u", opcode, data_len);

    node_link_msg_t message = {
        .header = {
            .opcode = opcode,
            .data_len = data_len,
            .extra_data_count = extra_data_1 ? 1 : 0,
        },
    };

    memcpy(message.data, data, data_len);

    if (extra_data_1) {
        message.extra_data[0].data = (uint8_t *) extra_data_1;
        message.extra_data[0].data_len = extra_data_1_len;
        message.extra_data[0].should_free_once_sent = should_free_once_sent;
    }

    return queue_try_add(&computer->message_queue, &message);
}
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

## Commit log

2026-09-14 Add kicad project
    [2_nodes_2_hid.kicad_pcb, 2_nodes_2_hid.kicad_sch]
2026-09-14 Update Kicad schematic, more compact design
    [2_nodes_2_hid.kicad_pcb, 2_nodes_2_hid.kicad_sch]
2026-09-16 Update PCB design, remove via on data tracks (inverted d+ and d-), add capacitor on usb ports
    [2_nodes_2_hid.kicad_pcb, 2_nodes_2_hid.kicad_sch]
2026-09-16 Rework PCB design, increase size of the VSYS track and GND to handle 100mA at 5V
    [2_nodes_2_hid.kicad_pcb, 2_nodes_2_hid.kicad_sch]
2026-09-17 Rework PCB design, add ground plane, make sure d+ and d- track have same length and other various fix
    [2_nodes_2_hid.kicad_pcb, 2_nodes_2_hid.kicad_sch]
2026-09-17 Update schematic to clarify where the capacitor need to be connected
    [2_nodes_2_hid.kicad_sch]
2026-09-17 Export the kicad schematic
2026-09-17 Fix error found by kicad DRC on the PCB
    [2_nodes_2_hid.kicad_pcb]
2026-09-17 Add missing GND connection for debug pins
    [2_nodes_2_hid.kicad_pcb, 2_nodes_2_hid.kicad_sch]
2026-09-22 Fix selector GPIO should be 1 when no transmission and 0 during transmission, only apply for 2 nodes+
    [node_link.c, node_link_ctrl.c]
2026-09-22 Fix inconsistent naming of DATA_AVAILABLE_GPIO
    [node_link_node.c]
2026-09-22 Print the computer_id on node received in the init message from controller
2026-09-22 Change method to drain rx/tx after an error during spi communication
    [node_link.c, node_link_node.c]
2026-09-22 Fix potential timing error at startup when waiting for nodes to be ready
    [node_link_ctrl.c]
2026-09-22 Add schematic and pcb design for 2 nodes with 3 hid and 3 hid with 3 nodes
    [2_nodes_3_hid.kicad_pcb, 2_nodes_3_hid.kicad_sch, 3_nodes_3_hid.kicad_pcb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]
